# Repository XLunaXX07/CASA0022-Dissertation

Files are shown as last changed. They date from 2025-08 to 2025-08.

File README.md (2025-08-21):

# From Light to Play  
### A Geodesic Dome Installation Combining LED Interaction and Web-Based Memory Games  

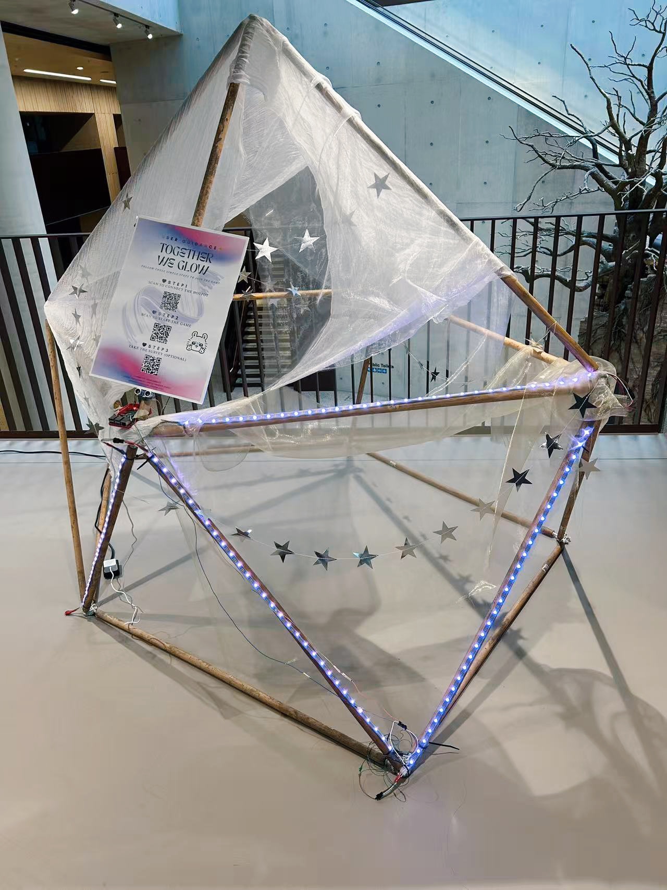
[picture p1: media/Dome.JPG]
  

*This project explores how LED-based interaction and gamification can enhance engagement in shared environments.  
The browser-based memory game integrated into this installation is titled **Together We Glow**.*

---

## What is this project?

This installation combines **LED light strips**, a **geodesic dome-inspired wooden frame**, and a **browser-based memory game** inspired by the classic **Simon Game** (the 1970s electronic memory game with colored buttons).  
It was deployed in a **semi-public indoor exhibition** as a prototype to test how gamification and light-based feedback can sustain engagement and encourage collaboration.

---

## System Architecture

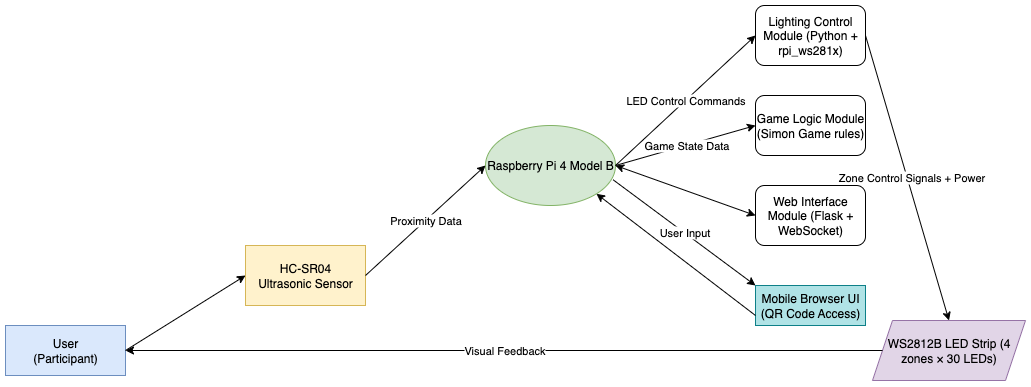
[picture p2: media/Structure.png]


- **Raspberry Pi 4B**: runs Python, Flask, WebSocket  
- **HC-SR04 ultrasonic sensor**: detects proximity  
- **WS2812B LED strips**: 4 zones (red, green, blue, yellow)  
- **Web interface**: mobile browser UI via QR code  

---

## Materials

- Raspberry Pi 4 Model B  
- WS2812B LED strips (4 × 30 LEDs)  
- HC-SR04 ultrasonic sensor  
- Breadboard, jumper wires, resistors (1kΩ × 2)  
- Wooden poles (repurposed broom handles) for the frame  

---

## Circuit Design  

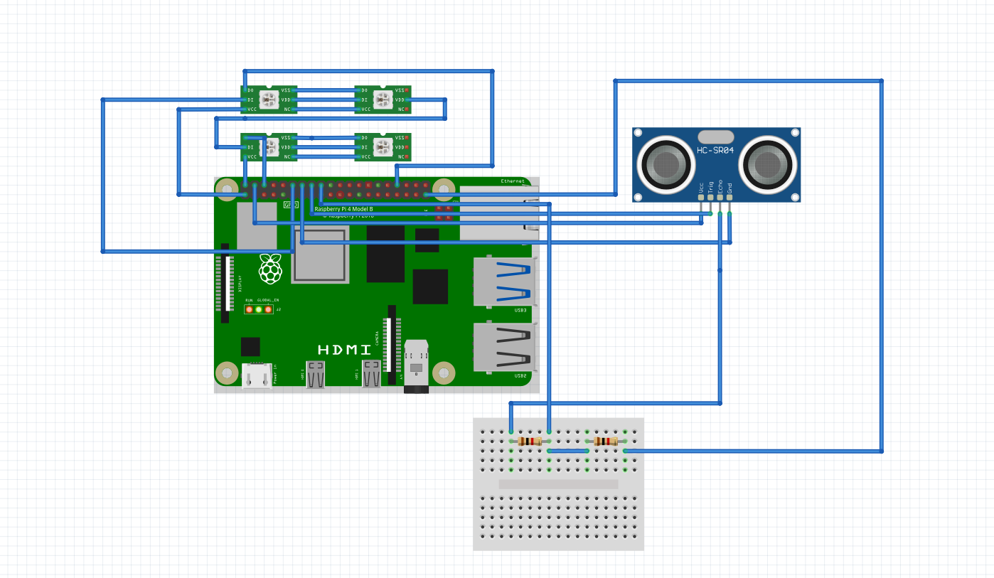
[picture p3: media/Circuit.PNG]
  
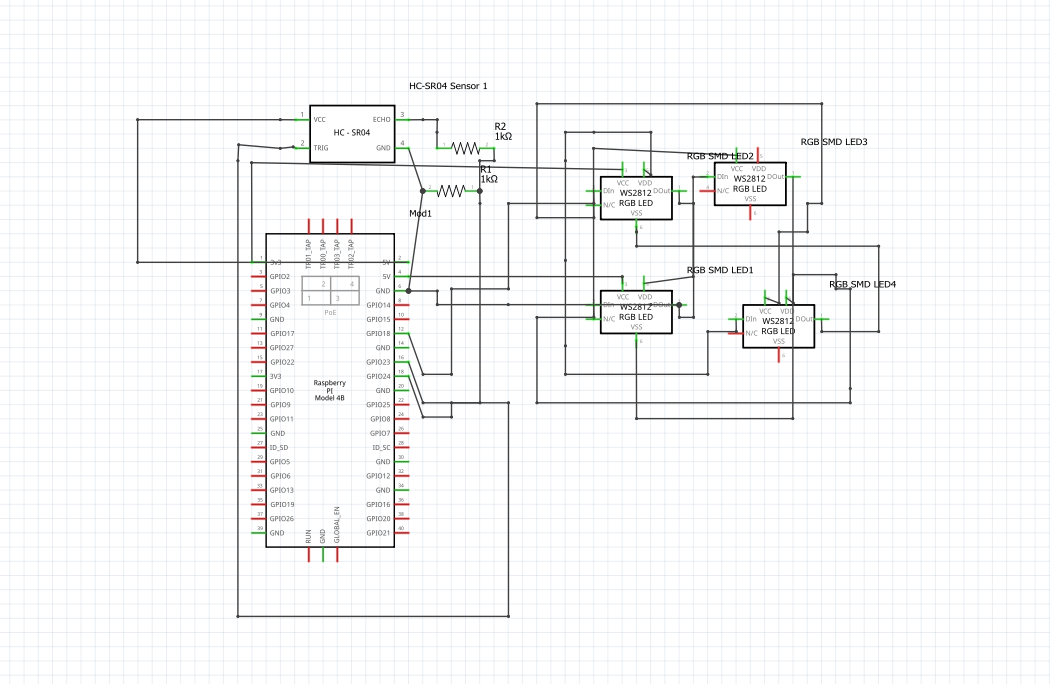
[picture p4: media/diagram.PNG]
  

**Prototype testing**  
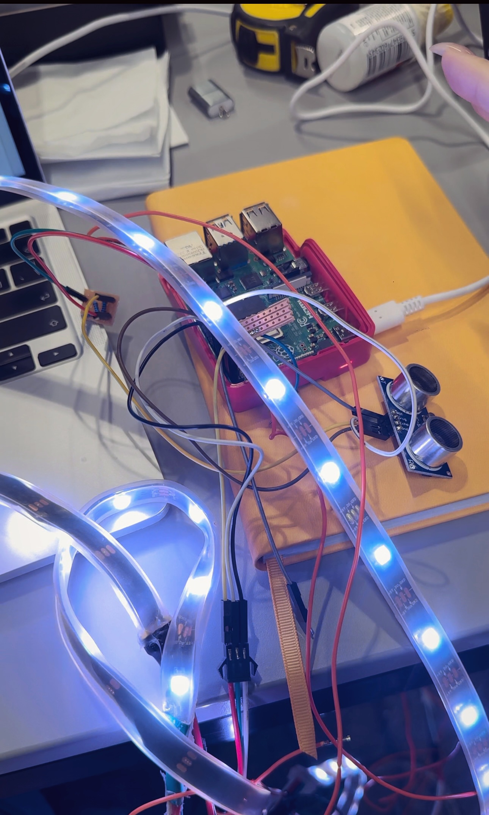
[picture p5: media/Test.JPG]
  

For reproducibility, the repository also includes a Fritzing project file [`dome_circuit_design.fzz`](dome_circuit_design.fzz), which contains:  

- **Breadboard view** – prototype wiring  
- **Schematic view** – logical circuit diagram  
- **PCB view** – potential printed circuit board layout  

Open with [Fritzing](https://fritzing.org/) to explore or modify the design.  

---

## Web Interface

**Homepage**  
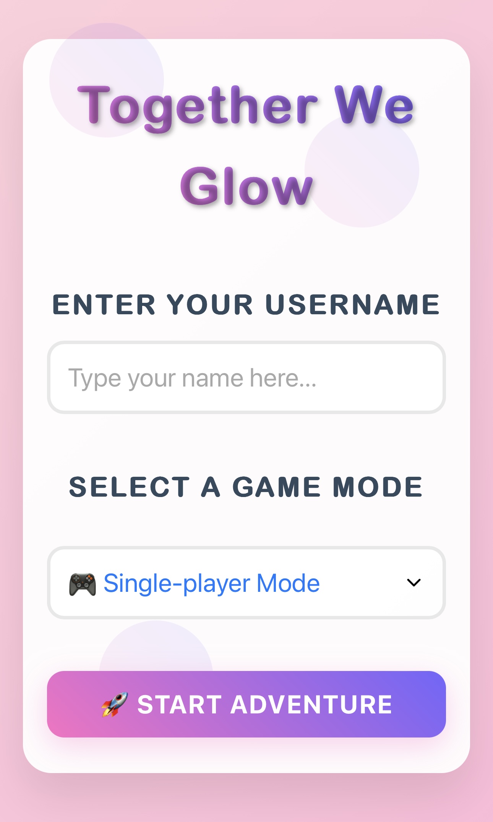
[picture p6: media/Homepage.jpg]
  

**Game**  
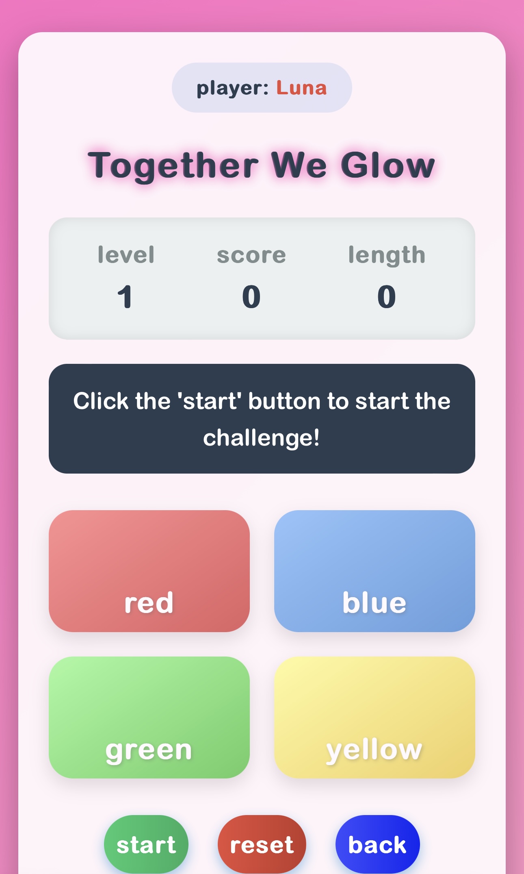
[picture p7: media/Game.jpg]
  

Players scan a QR code, enter a username, select **single-player or multi-player mode**, and follow the LED sequence in the memory game.

---

## Future Work

Based on feedback and exhibition testing, possible improvements include:  
- Expanding LED coverage to more struts for stronger visual impact  
- Adding **sound cues** for start/success/failure to enrich immersion  
- Optimising system stability and restart functions  
- Implementing **adaptive difficulty** to suit different user groups  
- Testing deployment in larger, public-facing environments  

---

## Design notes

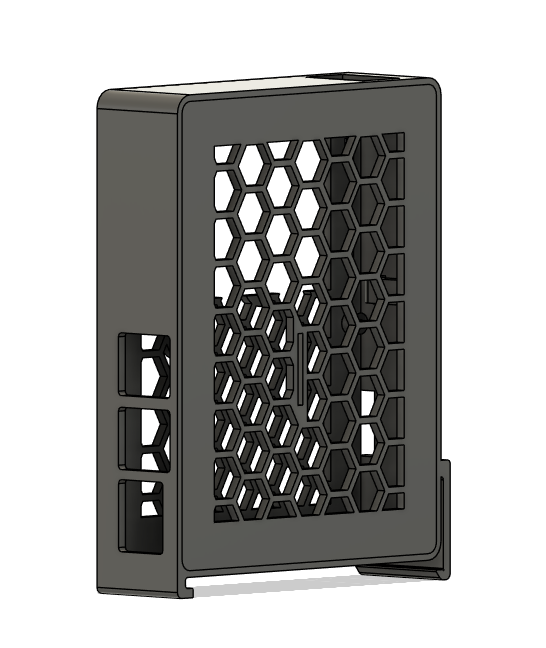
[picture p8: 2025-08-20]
media/CAD1.png

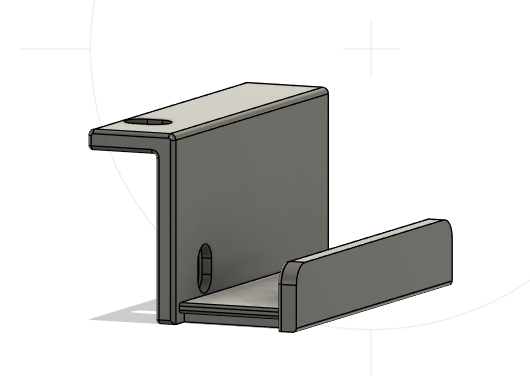
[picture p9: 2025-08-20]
media/CAD3.png

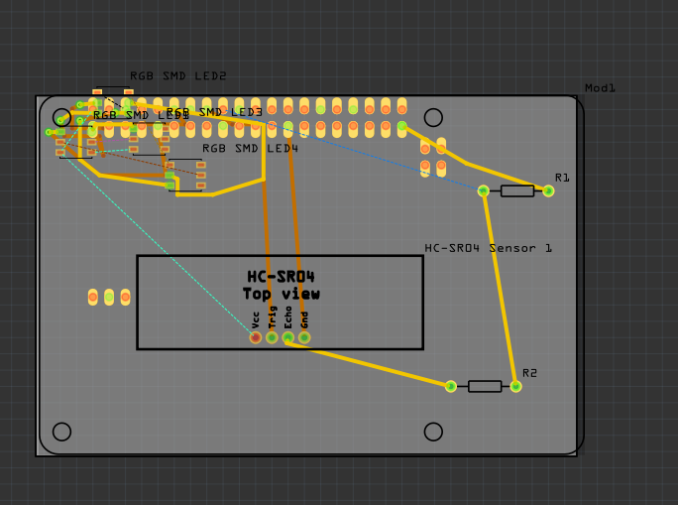
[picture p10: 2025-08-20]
media/PCB.PNG

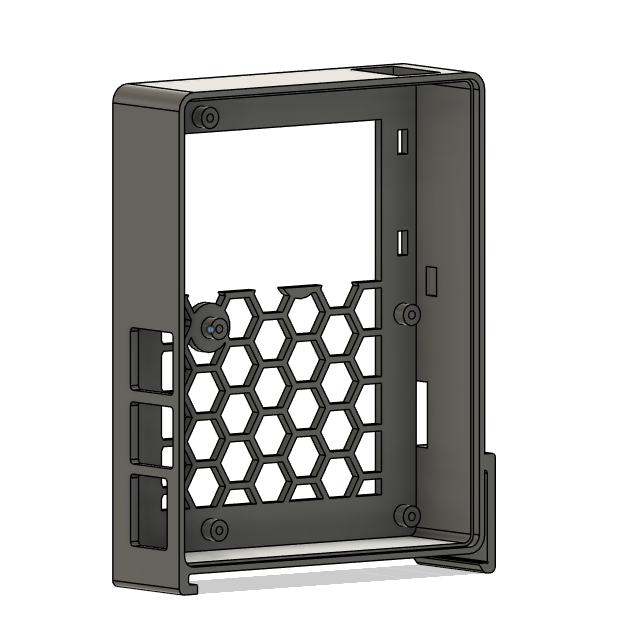
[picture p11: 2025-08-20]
media/CAD2.png

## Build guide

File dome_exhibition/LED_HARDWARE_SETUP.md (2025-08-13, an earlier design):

# LED Hardware Configuration Description

Hardware configuration

This project currently supports 120 LED light strips, which are divided into two 60-strip light strips:

Light strip configuration
- ** Light Strip 1**: 60 leds, connected to GPIO18, using channel 0
- ** Light Strip 2**: 60 leds, connected to GPIO23, using Channel 1

Color area distribution
Each color area now contains 30 leds (15 from each light strip) :

- ** Red Area **: LED 0-29 (0-14 of light Strip 1 + 0-14 of light strip 2
- ** Yellow area **: LED 30-59 (15-29 of Strip 1 + 15-29 of Strip 2)
- ** Blue area **: LED 60-89 (30-44 of light Strip 1 + 30-44 of light strip 2
- ** Green Area **: LED 90-119 (45-59 of light Strip 1 + 45-59 of light Strip 2

Hardware connection

Raspberry PI GPIO connection
` ` `
Light strip 1 (60 pieces)
- Data cable: GPIO18
- VCC: 5V
- GND: GND

2 light strips (60 pieces)
- Data cable: GPIO23
- VCC: 5V
- GND: GND
` ` `

### Precautions
1. Ensure that the two light strips use different GPIO pins
2. Use different DMA channels to avoid conflicts
3. Ensure sufficient power supply (it is recommended to use an external 5V power supply)
4. Do not make the data cable too long to avoid signal attenuation

Software Modification Instructions

Main modified contents
1. **led_controller.py**:
- Supports two independent light strip objects
Modify the area size to 30 leds
- Added LED index mapping logic
- Added hardware testing functionality

2. ** New File **:
- 'test_leds.py' : LED hardware test script
- 'LED_HARDWARE_SETUP.md' : This instruction manual

Test the hardware connection
Run the test script to verify the hardware connection
```bash
python3 test_leds.py
` ` `

The test contents include:
- Turn off all leds
Test each color area
- Test sequence playback
- Test the lighting of a single area

Troubleshooting

Frequently Asked Questions
1. ** Some leds do not light up **: Check the data cable connection and power supply
2. ** Color confusion **: Check the GPIO pin configuration
3. ** Flickering or unstable **: Check the stability of the power supply and the quality of the data cable
4. ** Completely unresponsive **: Check the Raspberry PI permissions and library installation

Debugging steps
Run the test script
2. Check the output information of the console
3. Confirm that the GPIO pin configuration is correct
4. Verify that the power supply is sufficient

"Performance Optimization suggestions.

1. ** Power Management **: Use an external 5V power supply to avoid insufficient power for the Raspberry PI
2. "Heat Dissipation" : Ensure that the LED light strips have sufficient heat dissipation
3. ** Brightness Adjustment **: Adjust the LED brightness setting according to the environment
4. ** Refresh Rate **: Adjust the LED signal frequency as needed

# LED硬件配置说明

## 硬件配置

本项目现在支持120盏LED灯带，分为两个60盏的灯带：

### 灯带配置
- **灯带1**: 60盏LED，连接到GPIO18，使用通道0
- **灯带2**: 60盏LED，连接到GPIO23，使用通道1

### 颜色区域分布
每个颜色区域现在包含30盏LED（15盏来自每个灯带）：

- **红色区域**: LED 0-29 (灯带1的0-14 + 灯带2的0-14)
- **黄色区域**: LED 30-59 (灯带1的15-29 + 灯带2的15-29)
- **蓝色区域**: LED 60-89 (灯带1的30-44 + 灯带2的30-44)
- **绿色区域**: LED 90-119 (灯带1的45-59 + 灯带2的45-59)

## 硬件连接

### 树莓派GPIO连接
```
灯带1 (60盏):
- 数据线: GPIO18
- VCC: 5V
- GND: GND

灯带2 (60盏):
- 数据线: GPIO23
- VCC: 5V
- GND: GND
```

### 注意事项
1. 确保两个灯带使用不同的GPIO引脚
2. 使用不同的DMA通道避免冲突
3. 确保电源供应足够（建议使用外部5V电源）
4. 数据线长度不要过长，避免信号衰减

## 软件修改说明

### 主要修改内容
1. **led_controller.py**: 
   - 支持两个独立的灯带对象
   - 修改区域大小为30盏LED
   - 添加了LED索引映射逻辑
   - 增加了硬件测试功能

2. **新增文件**:
   - `test_leds.py`: LED硬件测试脚本
   - `LED_HARDWARE_SETUP.md`: 本说明文档

### 测试硬件连接
运行测试脚本验证硬件连接：
```bash
python3 test_leds.py
```

测试内容包括：
- 关闭所有LED
- 测试各个颜色区域
- 测试序列播放
- 测试单个区域点亮

## 故障排除

### 常见问题
1. **部分LED不亮**: 检查数据线连接和电源供应
2. **颜色错乱**: 检查GPIO引脚配置
3. **闪烁或不稳定**: 检查电源稳定性和数据线质量
4. **完全无反应**: 检查树莓派权限和库安装

### 调试步骤
1. 运行测试脚本
2. 检查控制台输出信息
3. 确认GPIO引脚配置正确
4. 验证电源供应充足

## 性能优化建议

1. **电源管理**: 使用外部5V电源，避免树莓派电源不足
2. **散热**: 确保LED灯带有足够的散热
3. **亮度调节**: 根据环境调整LED亮度设置
4. **刷新率**: 根据需要调整LED信号频率

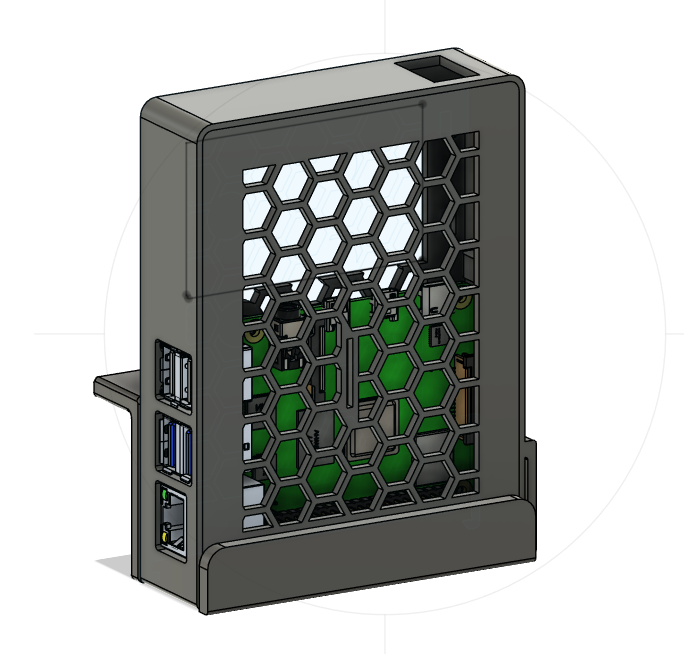
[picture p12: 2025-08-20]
media/3dPrinted.png

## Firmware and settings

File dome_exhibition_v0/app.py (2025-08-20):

import json
import socket
from flask_socketio import SocketIO, emit
from flask import Flask, render_template, jsonify, request, redirect, url_for, session
import random
import threading
import time
import led_controller



app = Flask(__name__)
app.config['SECRET_KEY'] = 'simon_game_secret'

# 初始化 SocketIO
socketio = SocketIO(app, async_mode='threading', cors_allowed_origins="*")

# 难度等级配置
# level,light_duration_per_color,off_duration_between_colors
level_duration_list = [
    (1, 1, 0.5),
    (2, 1, 0.5),
    (3, 1, 0.5),
    (4, 1, 0.5),
    (5, 1, 0.5),
    (6, 0.8, 0.4),
    (7, 0.8, 0.4),
    (8, 0.8, 0.4),
    (9, 0.6, 0.3),
    (10, 0.6, 0.3)
]

# ------------------ 多人模式 -------------------------
# 用户名存储
user_sessions = {}
# 房间状态管理
rooms = {}
# 全局变量
user_sids = {}  # { username: sid }


# 房间结构示例：
# rooms = {
#     "room1": {
#         "host": "player1",
#         "players": {
#             "player1": {"ready": False, "score": 0},
#             "player2": {"ready": False, "score": 0}
#         },
#         "game_active": False,
#         "current_level": 1,
#         "target_sequence": [],
#         "answers_received": {},  # { player: [sequence] }
#         "all_answered": False
#     }
# }
# 连接事件处理
@socketio.on('connect')
def handle_connect():
    print("socket[connect]without data, Client connected", request.sid)


@socketio.on('register_user')
def handle_register_user(data):
    print("socket[register_user]with data:", data)
    username = data.get('username')
    if username:
        user_sids[username] = request.sid
        print(f"SID 注册成功: {username} -> {request.sid}")

@socketio.on('disconnect')
def handle_disconnect():
    print("socket[disconnect]without data,Client disconnected:", request.sid)
    # 查找该 sid 对应的用户名
    for username, sid in user_sids.items():
        if sid == request.sid:
            print(f"将要删除用户 {username}")
            for room in list(rooms.keys()):
                if username in rooms[room]['players']:
                    del rooms[room]['players'][username]
                    # 如果是房主，则更新房主或删除空房间
                    if rooms[room]['host'] == username:
                        remaining = list(rooms[room]['players'].keys())
                        if remaining:
                            rooms[room]['host'] = remaining[0]
                        else:
                            del rooms[room]
                            print(f"已删除空房间: {room}")
                            break
                socketio.emit('update_players', {
                    'players': rooms[room]['players'],
                    'host': rooms[room]['host']
                })

            print(f"User {username} 已从所有房间中移除")
            user_sids.pop(username, None)
            break

# 加入房间
@socketio.on('join_room')
def join_room(data):
    print("socket[join_room]with data:", data)
    username = data.get('username')
    room = data.get('room', 'default_room')

    print(f"{username} 加入 {room}")

    if room in rooms and rooms[room]['game_active']:
        # 游戏已经开始，不允许加入
        socketio.emit('join_denied', {
            'message': '游戏已经开始，无法加入'
        }, to=request.sid)
        return

    if room not in rooms:
        rooms[room] = {
            'host': username,
            'players': {},
            'game_active': False,
            'current_level': 1,
            'target_sequence': [],
            'answers_received': {},
            'all_answered': False
        }

    rooms[room]['players'][username] = {'ready': False, 'score': 0}

    # 更新房间信息
    socketio.emit('update_players', {
        'players': rooms[room]['players'],
        'host': rooms[room]['host']
    })

@socketio.on('set_ready')
def handle_set_ready(data):
    print("socket[set_ready]with data:", data)
    username = data['username']
    room = data['room']
    if room in rooms:
        room_data = rooms[room]
        if username in room_data['players']:
            room_data['players'][username]['ready'] = True

            socketio.emit('update_players', {
                'players': rooms[room]['players'],
                'host': rooms[room]['host']
            })


@socketio.on('start_game')
def handle_start_game(data):
    print("socket[start_game]with data:", data)
    # 延迟2s再开始
    time.sleep(1)
    room = data['room']
    if room in rooms:
        room_data = rooms[room]
        if room_data['host'] == data['username']:
            room_data['game_active'] = True
            room_data['current_level'] = 1
            room_data['target_sequence'] = game_state.generate_sequence(1)

            # 模拟树莓派处理线程
            threading.Thread(target=simulate_raspberry_processing_multi, args=(room,room_data['current_level'], room_data['target_sequence'],)).start()

            socketio.emit('game_started', {
                'level': room_data['current_level'],
                'sequence': room_data['target_sequence']
            })


def update_user_score(room, username, score_change):
    """
    更新指定用户的分数，并广播给房间所有人
    :param room: 房间名
    :param username: 用户名
    :param score_change: 要增加的分数
    """
    if room in rooms and username in rooms[room]['players']:
        rooms[room]['players'][username]['score'] += score_change
        socketio.emit('update_score', {
            'username': username,
            'score': rooms[room]['players'][username]['score']
        })


@socketio.on('submit_answer')
def handle_submit_answer(data):
    print("socket[submit_answer]with data:", data)
    username = data['username']
    room = data['room']
    answer = data['answer']

    if room in rooms:
        room_data = rooms[room]
        room_data['answers_received'][username] = answer

        # 判断是否全部回答完成
        if len(room_data['answers_received']) == len(room_data['players']):
            # 告诉其他用户开始查看led灯
            socketio.emit('write_messageBox', {
                'message': 'Observe the light!'
            })
            evaluate_all_answers(room)
        else:
            # 告诉用户还需要等待其他人
            socketio.emit('write_messageBox', {
                'message': 'Waiting for other players...'
            }, to=request.sid)

# 评估所有回答，更新分数，并进入下一轮
def evaluate_all_answers(room):
    room_data = rooms[room]
    correct_sequence = room_data['target_sequence']

    for user, ans in room_data['answers_received'].items():
        if ans == correct_sequence:
            room_data['players'][user]['score'] += 10 + (room_data['current_level'] * 10)
            update_user_score(room, user, room_data['players'][user]['score'])
        else:
            pass

    # 更新关卡和状态
    room_data['current_level'] += 1
    room_data['answers_received'] = {}

    if room_data['current_level'] > 10:
        # 游戏结束
        end_game(room)
    else:
        # 延迟2s
        time.sleep(1)
        # 进入下一关
        print("[evaluate_all_answers]进入第{0}关".format(room_data['current_level']))
        next_seq = game_state.generate_sequence(room_data['current_level'])
        room_data['target_sequence'] = next_seq
        threading.Thread(target=simulate_raspberry_processing_multi, args=(room,room_data['current_level'], next_seq,)).start()


# 游戏结束广播
def end_game(room):
    print("[end_game]游戏结束")
    room_data = rooms[room]
    socketio.emit('game_over', {
        'scores': {u: p['score'] for u, p in room_data['players'].items()}
    })

    # 删除房间
    if room in rooms:
        del rooms[room]




# 树莓派处理模拟
def simulate_raspberry_processing_multi(room, level, sequence):
    # 播放序列
    led_controller.play_sequence(sequence, light_duration_per_color=level_duration_list[level-1][1], off_duration_between_colors=level_duration_list[level-1][2])

    # led_controller.play_sequence(sequence, light_duration_per_color=0.8, off_duration_between_colors=0.2)
    print(f"树莓派序列处理完成: {sequence}")
    if room not in rooms:
        print("[simulate_raspberry_processing_multi]房间不存在")
        return
    room_data = rooms[room]

    # 通知前端：树莓派已完成序列显示，现在可以开始输入
    notify_frontend({
        'status': 'ready_for_input',
        'level': room_data['current_level'],
        'sequence': sequence
    })



# -------------------------- 主页 --------------------------
@app.route('/mode_selection')
def mode_selection():
    return render_template('mode_selection.html')


@app.route('/api/save_username', methods=['POST'])
def save_username():
    data = request.json
    username = data.get('username')

    if not username or len(username.strip()) == 0:
        return jsonify({'error': '用户名不能为空'}), 400

    session['username'] = username
    user_sessions[username] = {'score': 0, 'level': 1}

    return jsonify({
        'status': 'success',
        'username': username
    })


@app.route('/api/select_mode', methods=['POST'])
def select_mode():
    data = request.json
    mode = data.get('mode')  # 'single' or 'multi'
    username = session.get('username', 'tourist')

    if not username or mode not in ['single', 'multi']:
        return jsonify({'error': 'Invalid input'}), 400

    # 保存用户名和模式（可选）
    session['player_name'] = username
    session['game_mode'] = mode

    # 返回对应的页面路径
    return jsonify({
        'redirect': '/single' if mode == 'single' else '/multi',
        'username': username,
        'mode': mode
    })


@app.route('/single')
def single_player():
    username = session.get('username', 'tourist')
    return render_template('single.html', player_name=username, game_mode='single')


@app.route('/multi')
def multi_player():
    username = session.get('username', 'tourist')
    return render_template('multi.html', player_name=username, game_mode='multi')
    # return f"欢迎 {username} 进入【多人模式】页面！"

@app.route('/')
def index():
    return render_template('mode_selection.html')

# ---------------------------- 单人模式 ---------------------------------

# 游戏状态管理
class GameState:
    def __init__(self):
        self.current_level = 1
        self.target_sequence = []
        self.player_sequence = []
        self.player_score = 0
        self.game_active = False

    def generate_sequence(self, level=None):
        """生成新的颜色序列"""
        level = level or self.current_level
        colors = ['red', 'blue', 'green', 'yellow']
        seq_length = min(2 + level, 10)  # 序列长度随关卡增加
        self.target_sequence = random.choices(colors, k=seq_length)
        print("生成新序列:", self.target_sequence)
        self.player_sequence = []
        return self.target_sequence

    def reset_game(self):
        """重置游戏状态"""
        self.current_level = 1
        self.player_score = 0   
        self.game_active = False
        self.target_sequence = []
        self.player_sequence = []

    def check_sequence(self, player_sequence):
        """验证玩家序列并更新分数"""
        print("对比玩家输入序列:", player_sequence)
        print("目标序列:", self.target_sequence)
        if player_sequence == self.target_sequence:
            # 计算分数：基础分 + 关卡加成
            self.player_score += 10 + (self.current_level * 10)
            self.current_level += 1
            return True
        self.game_active = False
        return False

# 全局游戏状态实例
game_state = GameState()


# API端点实现
@app.route('/api/game/start', methods=['POST'])
def start_game():
    """开始新游戏"""
    game_state.reset_game()
    game_state.game_active = True
    sequence = game_state.generate_sequence()

    # 延迟2s
    time.sleep(1)

    # 模拟树莓派处理线程
    threading.Thread(target=simulate_raspberry_processing, args=(game_state.current_level, sequence,)).start()

    return jsonify({
        'status': 'started',
        'level': game_state.current_level,
        'sequence': sequence,
        'score': game_state.player_score
    })


@app.route('/api/game/check', methods=['POST'])
def check_sequence():
    """验证玩家输入的序列"""
    if not game_state.game_active:
        return jsonify({'error': 'Game not active'}), 400

    data = request.json
    player_sequence = data.get('playerSequence', [])

    if game_state.check_sequence(player_sequence):
        return jsonify({
            'result': 'correct',
            'score': game_state.player_score,
            'nextLevel': game_state.current_level
        })
    else:
        return jsonify({
            'result': 'incorrect',
            'final_score': game_state.player_score,
            'max_level': game_state.current_level - 1
        })


@app.route('/api/game/sequence', methods=['GET'])
def get_sequence():
    """获取指定关卡的新序列"""
    # 延迟1s
    time.sleep(1)

    level = request.args.get('level', type=int, default=game_state.current_level)
    sequence = game_state.generate_sequence(level)

    # 模拟树莓派处理线程
    threading.Thread(target=simulate_raspberry_processing, args=(level, sequence,)).start()

    return jsonify({
        'sequence': sequence,
        'level': level
    })


@app.route('/api/game/reset', methods=['POST'])
def reset_game():
    """重置游戏状态"""
    game_state.reset_game()
    return jsonify({'status': 'reset', 'score': 0, 'level': 1})

# 树莓派处理模拟
def simulate_raspberry_processing(level, sequence):

    # 播放序列
    led_controller.play_sequence(sequence, light_duration_per_color=level_duration_list[level-1][1], off_duration_between_colors=level_duration_list[level-1][2])
    print(f"树莓派序列处理完成: {sequence}")

    # 通知前端：树莓派已完成序列显示，现在可以开始输入
    notify_frontend({
        'status': 'ready_for_input',
        'level': game_state.current_level,
        'sequence': sequence
    })

def notify_frontend(message):
    """通过WebSocket向前端发送实时通知"""
    socketio.emit('game_update', message)
    print(f"已通过WebSocket发送通知到前端: {message}")


if __name__ == '__main__':
    # threading.Thread(target=start_socket_server, daemon=True).start()
    # app.run(host='0.0.0.0', port=5001, debug=True)
    socketio.run(app, host='0.0.0.0', port=5000, allow_unsafe_werkzeug = True, debug = True)

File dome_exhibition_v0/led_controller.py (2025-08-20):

import time

# Attempt to import rpi_ws281x for LED control.
# If not on a Raspberry Pi, a dummy class will be used.
try:
    from rpi_ws281x import PixelStrip, Color
    print("rpi_ws281x imported successfully.")
    IS_RPI_ENV = True
except ImportError:
    print("rpi_ws281x not found. Running in non-Raspberry Pi environment. LED control will be simulated.")
    IS_RPI_ENV = False

    # Dummy classes for non-Raspberry Pi environment
    class Color:
        def __init__(self, r, g, b):
            pass

    class PixelStrip:
        def __init__(self, *args, **kwargs):
            pass
        def begin(self):
            pass
        def setPixelColor(self, index, color):
            pass
        def show(self):
            pass

# --- LED Configuration ---
LED_COUNT = 60      # 总共60个灯珠
LED_PIN = 18        # 连接到像素的GPIO引脚 (18使用PWM!)
LED_FREQ_HZ = 800000 # LED信号频率（赫兹）(通常为800khz)
LED_DMA = 10        # 用于生成信号的DMA通道 (尝试10)
LED_BRIGHTNESS = 50 # 亮度设置 (0最暗，255最亮)
LED_INVERT = False  # 是否反转信号 (使用NPN晶体管电平转换时设为True)
LED_CHANNEL = 0

# Basic Color Definitions
RED_COLOR = Color(255, 0, 0)
YELLOW_COLOR = Color(255, 200, 0)
BLUE_COLOR = Color(0, 0, 255)
GREEN_COLOR = Color(0, 255, 0)
OFF_COLOR = Color(0, 0, 0)

# Zone Definitions (each zone 15 LEDs)
ZONE_SIZE = 15
ZONES = {
    'red': (0, ZONE_SIZE),            # 0-14
    'yellow': (ZONE_SIZE, ZONE_SIZE * 2),    # 15-29
    'blue': (ZONE_SIZE * 2, ZONE_SIZE * 3),  # 30-44
    'green': (ZONE_SIZE * 3, ZONE_SIZE * 4) # 45-59
}

# Create LED strip object
strip = None
if IS_RPI_ENV:
    strip = PixelStrip(LED_COUNT, LED_PIN, LED_FREQ_HZ, LED_DMA, LED_INVERT, LED_BRIGHTNESS, LED_CHANNEL)
    strip.begin()
    print("LED strip initialized on Raspberry Pi.")
else:
    print("LED strip not initialized (not on Raspberry Pi).")

# --- LED Control Functions ---
def get_color_object(color_name):
    """根据颜色名称返回颜色对象。"""
    colors = {
        'red': RED_COLOR,
        'yellow': YELLOW_COLOR,
        'blue': BLUE_COLOR,
        'green': GREEN_COLOR
    }
    return colors.get(color_name, OFF_COLOR)

def light_zone(zone_name, duration=0.8):
    """
    点亮指定LED区域并持续一段时间。
    参数:
        zone_name (str): 区域名称 ('red', 'yellow', 'blue', 'green')。
        duration (float): 区域保持点亮的时间，单位为秒。
    """
    color = get_color_object(zone_name)
    if not IS_RPI_ENV:
        print(f"模拟LED: 点亮区域 {zone_name}，颜色 {color}，持续 {duration} 秒")
        time.sleep(duration)
        return

    if zone_name not in ZONES:
        print(f"错误: 区域 '{zone_name}' 未定义。")
        return

    start, end = ZONES[zone_name]
    for i in range(start, end):
        strip.setPixelColor(i, color)
    strip.show()
    time.sleep(duration)

def turn_off_zone(zone_name):
    """
    关闭指定LED区域。
    参数:
        zone_name (str): 要关闭的区域名称。
    """
    if not IS_RPI_ENV:
        print(f"模拟LED: 关闭区域 {zone_name}")
        return

    if zone_name not in ZONES:
        print(f"错误: 区域 '{zone_name}' 未定义。")
        return

    start, end = ZONES[zone_name]
    for i in range(start, end):
        strip.setPixelColor(i, OFF_COLOR)
    strip.show()

def turn_off_all_leds():
    """关闭灯带上的所有LED。"""
    if not IS_RPI_ENV:
        print("模拟LED: 关闭所有LED。")
        return
    for i in range(LED_COUNT):
        strip.setPixelColor(i, OFF_COLOR)
    strip.show()
    print("所有LED已关闭。")

def play_sequence(sequence, light_duration_per_color=0.8, off_duration_between_colors=0.2):
    """
    在LED灯带上播放颜色序列。
    对于序列中的每个颜色，它会点亮相应的区域，
    然后关闭该区域，并在两者之间有短暂的暂停。
    最后，它确保所有LED都已关闭。

    参数:
        sequence (list): 颜色名称列表 (例如, ['red', 'blue', 'yellow'])。
        light_duration_per_color (float): 每个LED区域保持点亮的时间 (秒)。
        off_duration_between_colors (float): 关闭一个区域与点亮序列中下一个区域之间的时间 (秒)。
    """
    print(f"播放LED序列: {sequence}")
    for color_name in sequence:
        light_zone(color_name, light_duration_per_color)
        turn_off_zone(color_name)
        time.sleep(off_duration_between_colors) # 颜色之间的小暂停

    turn_off_all_leds() # 确保在序列播放结束时所有LED都已关闭
    print("LED序列播放完成。")


# Call turn_off_all_leds when the module is imported or script exits
# This ensures LEDs are off when the application stops

# import atexit
# if IS_RPI_ENV:
#     atexit.register(turn_off_all_leds)
